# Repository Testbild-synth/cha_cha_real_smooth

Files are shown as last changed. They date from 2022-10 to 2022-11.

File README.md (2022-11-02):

# 4HP version of Voxmachina ChaCha VCLFO Eurorack module
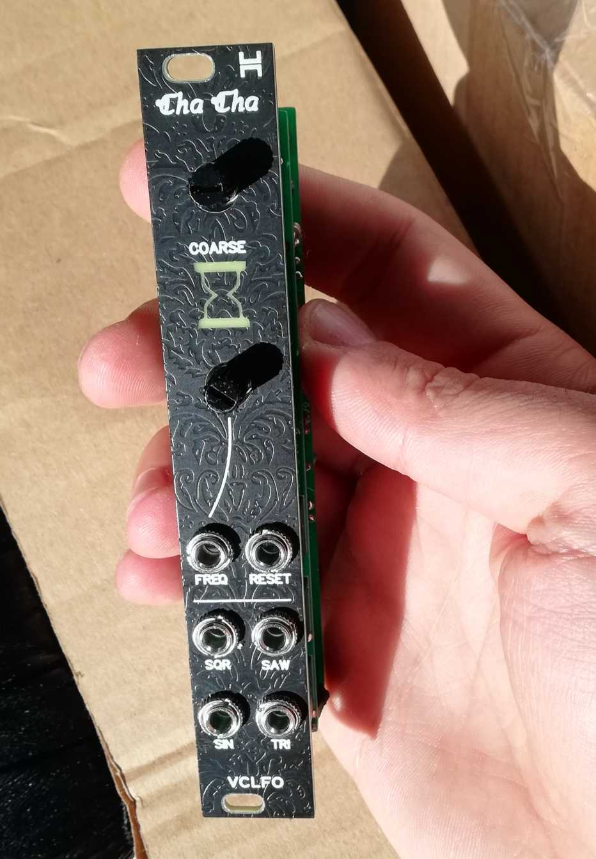
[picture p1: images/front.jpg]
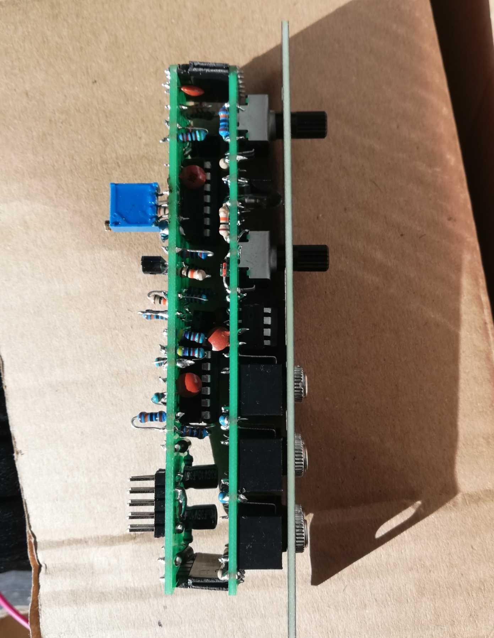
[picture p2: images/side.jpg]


This project is a 4HP fork of the Voxmachina chacha VCLFO eurorack module.

## Status: Confirmed working!

## Hardware and PCB

I had it in my head to do this in 4hp, but it was quite a pain.
In the end i had to fit a lot of standing resistors which I usually dislike but i think
I spaced them in a way that wasn't too confusing.

You can simply order the pcbs as-is on any pcb manufacturing site, 
I use jlcpcb. You can order all the pcbs with the standard settings.If for some reason the dimensions for the front panel
are not entered (happens to me sometimes on jlc), put them as 128.5x20mm.

  

The build is relatively straight forward, apart from the standing resistors which are kind of annoying.

schematic and bom are split between the two boards, as that's how voxmachina had his project set up. So just order components from both bom files

# Tuning
I simplified the sin shaping circuit so there is only one trimmer (for the saw shaper).
As for how to tune it, check out [voxmachina's videos on the module on youtube](https://www.youtube.com/watch?v=DsVzbcYWhuM&t=31s).

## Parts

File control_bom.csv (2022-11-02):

Name | Designator | Footprint | Quantity
0.1uf capacitor | C6,C7,C12 | RAD-0.1 | 3
CVIN, RESET, SINE, TRI, SQR, SAWUP | CV1, CV2, OUT1, OUT2, OUT3, OUT4 | THONKICONN | 6
1N4148 | D1,D5 | DO-35_BD2.0-L4.0-P8.00-D0.5-FD | 2
2.54mm header (female) 1x6 | H1 | 2.54mm header (female) 1x6 | 1
2.54mm header (female) 1x6 | H2 | 2.54mm header (female) 1x6 | 1
LED 5mm | LD1 | LED-TH_BD4.1-P2.00-D0.5-RD_RED | 1
BC550/BC548/equivalent | Q1,Q3 | BC547 | 2
4.7k resistor | R1 | AXIAL-0.3EZ | 1
330k resistor | R2 | AXIAL-0.3EZ | 1
B100k Potentiometer R09 | R3,R11 | R09-5KΩ | 2
100k resistor | R4,R8,R10,R14 | AXIAL-0.3EZ | 4
47k resistor | R5 | AXIAL-0.3EZ | 1
1k resistor | R7,R19,R20,R30,R41 | AXIAL-0.3EZ | 5
3.3k resistor | R17 | AXIAL-0.3EZ | 1
10k resistor | R21 | AXIAL-0.3EZ | 1
TL072 | IC1 | DIL08 | 1

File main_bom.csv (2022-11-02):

Name | Designator | Footprint | Quantity
10uF electrolytic capacitor | C1,C4,C8 | CAP-TH_BD5.0-P2.00-D0.8-FD | 3
0.1uf capacitor | C2,C3,C6,C7,C10 | RAD-0.1 | 5
1N4148 diode | D1,D2 | DO-35_BD2.0-L4.0-P8.00-D0.5-FD | 2
1N5819 diode | D3,D4 | DO-41_BD2.4-L4.7-P8.70-D0.9-RD | 2
2.54mm header (male) 6 pins | H1 | HDR-F-2.54_1X6 | 1
2.54mm header (male) 6 pins | H2 | HDR-F-2.54_1X6 | 1
Eurorack power header/2x5 header | P1 | EURORACK SHROUDED POWER 10 PIN | 1
BC550/BC548/equivalent | Q1,Q2 | TO92-X | 2
1k resistor | R1 | RESISTOR-VERTICAL | 1
10k resistor | R2,R14,R16,R20 | RESISTOR-VERTICAL | 4
39k resistor | R3 | RESISTOR-VERTICAL | 1
100k resistor | R4,R6,R7,R8,R15,R17,R19,R22 | RESISTOR-VERTICAL | 8
22k resistor | R5 | RESISTOR-VERTICAL | 1
47k resistor | R9,R10,R11,R12,R13 | RESISTOR-VERTICAL | 5
20k resistor | R18 | RESISTOR-VERTICAL | 1
51k resistor | R21 | RESISTOR-VERTICAL | 1
10 ohm resistor | R23,R24 | AXIAL-0.3 | 2
20k Trimpot | TM1 | TRIMPOT | 1
TL074 | U1,U2 | DIP-14 | 2

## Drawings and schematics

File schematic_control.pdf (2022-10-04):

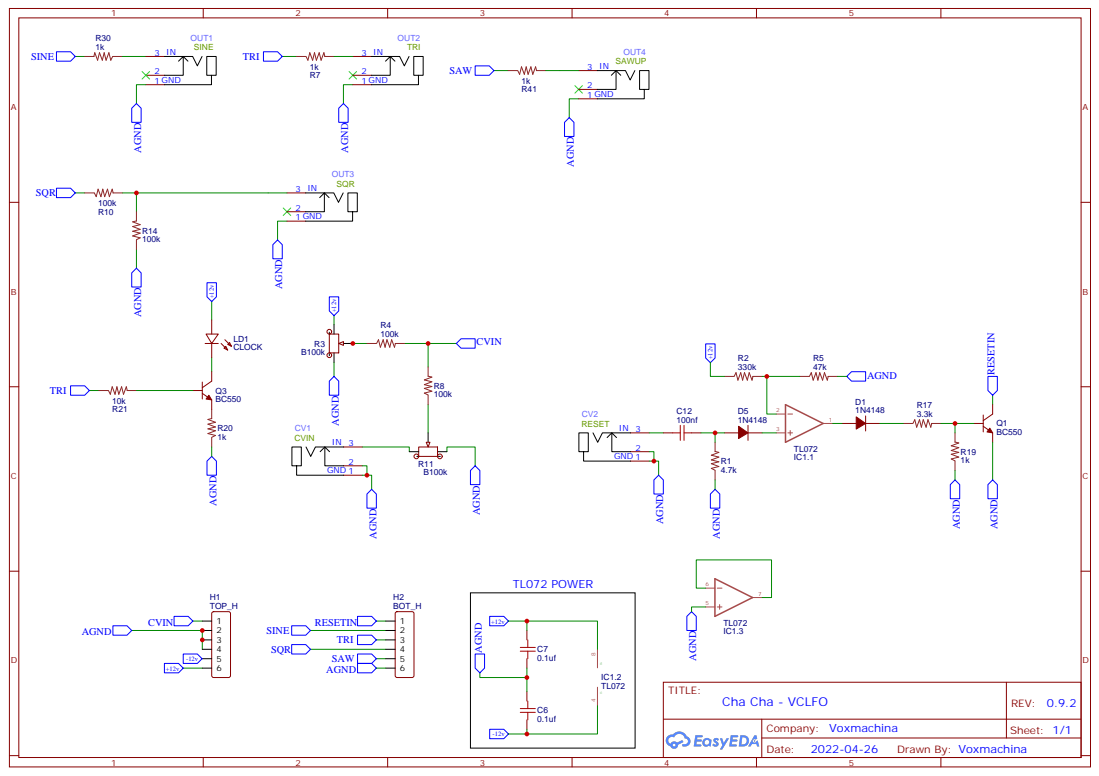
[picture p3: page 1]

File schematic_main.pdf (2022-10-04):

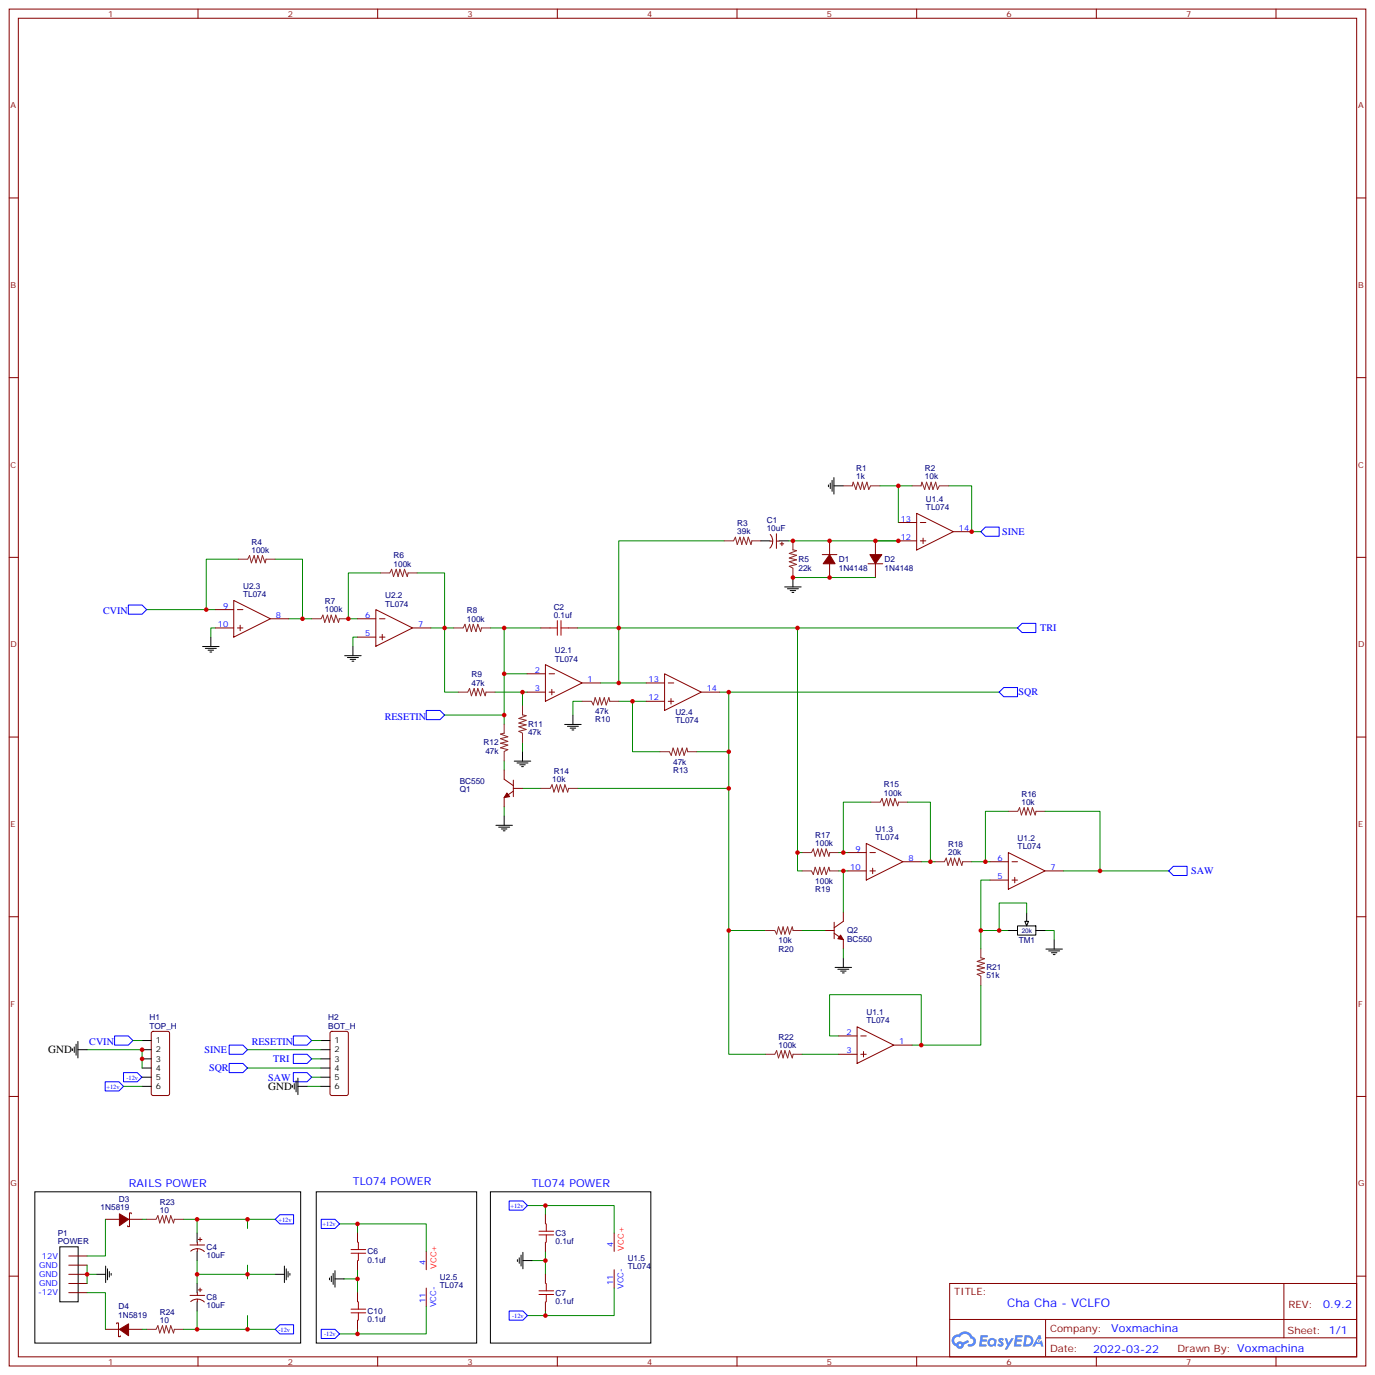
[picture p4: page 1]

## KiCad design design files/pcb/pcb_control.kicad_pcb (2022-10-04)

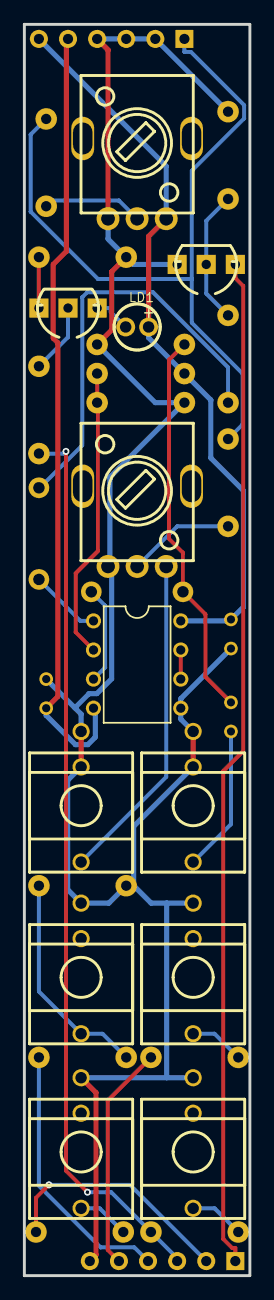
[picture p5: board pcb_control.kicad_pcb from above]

Board: 2 copper layers, 19.7 x 109.2 mm, 33 parts (0 on the bottom side), 27 nets.

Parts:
C6, C7, C12: 0.1uf; RAD-0.1
CV1: CVIN; THONKICONN
CV2: RESET; THONKICONN
D1, D5: 1N4148; DO-35_BD2.0-L4.0-P8.00-D0.5-FD
H1: TOP_H; HDR-F-2.54_1X6
H2: BOT_H; HDR-F-2.54_1X6
IC1: TL072; DIL08
LD1: CLOCK; LED-TH_BD4.1-P2.00-D0.5-RD_RED
OUT1: SINE; THONKICONN
OUT2: TRI; THONKICONN
OUT3: SQR; THONKICONN
OUT4: SAWUP; THONKICONN
Q1, Q3: BC550; BC547
R1: 4.7k; AXIAL-0.3EZ
R2: 330k; AXIAL-0.3EZ
R3, R11: B100k; R09-5KΩ
R4, R8, R10, R14: 100k; AXIAL-0.3EZ
R5: 47k; AXIAL-0.3EZ
R7, R19, R20, R30, R41: 1k; AXIAL-0.3EZ
R17: 3.3k; AXIAL-0.3EZ
R21: 10k; AXIAL-0.3EZ

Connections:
+12V: C7.2, H1.6, IC1.8, LD1.2, R2.1, R3.3
-12V: C6.1, H1.5, IC1.4
AGND: C6.2, C7.1, CV1.1, CV1.2, CV2.1, CV2.2, H1.2, H1.3, H1.4, H2.6, IC1.5, OUT1.1, OUT2.1, OUT3.1, OUT4.1, Q1.3, R1.1, R3.1, R5.2, R11.1, R14.1, R19.1, R20.1
C12_2: C12.2, D5.1, R1.2
CV1_3: CV1.3, R11.3
CV2_3: C12.1, CV2.3
CVIN: H1.1, R4.2, R8.2
D5_2: D5.2, IC1.3
IC1_1: D1.1, IC1.1
IC1_2: IC1.2, R2.2, R5.1
IC1_6: IC1.6, IC1.7
Q3_1: LD1.1, Q3.1
Q3_2: Q3.2, R21.2
R4_1: R3.2, R4.1
R7_2: OUT2.3, R7.2
R8_1: R8.1, R11.2
R14_2: OUT3.3, R10.2, R14.2
R17_1: D1.2, R17.1
R17_2: Q1.2, R17.2, R19.2
R20_2: Q3.3, R20.2
R30_1: OUT1.3, R30.1
R41_2: OUT4.3, R41.2
RESETIN: H2.1, Q1.1
SAW: H2.5, R41.1
SINE: H2.2, R30.2
SQR: H2.4, R10.1
TRI: H2.3, R7.1, R21.1

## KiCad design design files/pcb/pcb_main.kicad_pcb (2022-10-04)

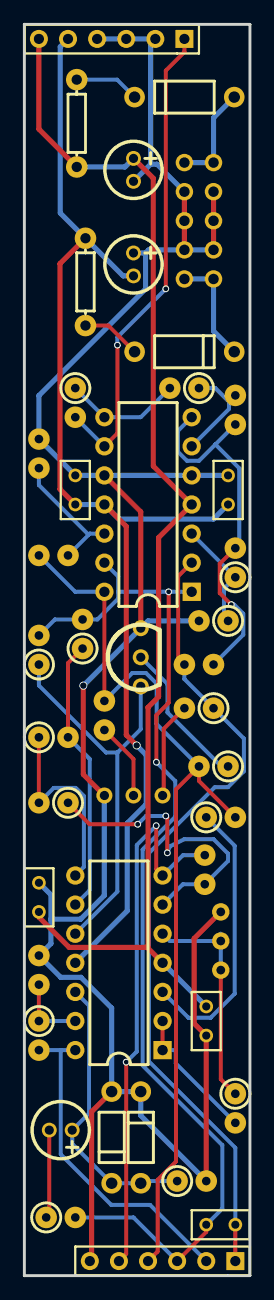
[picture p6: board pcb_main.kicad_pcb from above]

Board: 2 copper layers, 19.7 x 109.2 mm, 44 parts (0 on the bottom side), 31 nets.

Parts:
C1, C4, C8: 10uF; CAP-TH_BD5.0-P2.00-D0.8-FD
C2, C3, C6, C7, C10: 0.1uf; RAD-0.1
D1, D2: 1N4148; DO-35_BD2.0-L4.0-P8.00-D0.5-FD
D3, D4: 1N5819; DO-41_BD2.4-L4.7-P8.70-D0.9-RD
H1: TOP_H; HDR-F-2.54_1X6
H2: BOT_H; HDR-F-2.54_1X6
P1: POWER; EURORACK SHROUDED POWER 10 PIN
Q1, Q2: BC550; TO92-X
R1: 1k; RESISTOR-VERTICAL
R2, R14, R16, R20: 10k; RESISTOR-VERTICAL
R3: 39k; RESISTOR-VERTICAL
R4, R6, R7, R8, R15, R17, R19, R22: 100k; RESISTOR-VERTICAL
R5: 22k; RESISTOR-VERTICAL
R9, R10, R11, R12, R13: 47k; RESISTOR-VERTICAL
R18: 20k; RESISTOR-VERTICAL
R21: 51k; RESISTOR-VERTICAL
R23, R24: 10; AXIAL-0.3
TM1: 20k; TRIMPOT
U1, U2: TL074; DIP-14

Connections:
+12V: C3.2, C4.1, C6.2, H1.6, R23.2, U1.4, U2.4
-12V: C7.1, C8.2, C10.1, H1.5, R24.2, U1.11, U2.11
CVIN: H1.1, R4.1, U2.9
D3_1: D3.1, R23.1
D4_2: D4.2, R24.1
GND: C3.1, C4.2, C6.1, C7.2, C8.1, C10.2, D1.1, D2.2, H1.2, H1.3, H1.4, H2.6, P1.2, P1.3, P1.4, Q1.3, Q2.3, R1.2, R5.1, R10.1, R11.1, TM1.1, U2.5, U2.10
P1_1: D3.2, P1.1
P1_5: D4.1, P1.5
Q1_1: Q1.1, R12.1
Q2_2: Q2.2, R20.2
R3_2: C1.2, R3.2
R6_1: R6.1, R7.2, U2.6
R7_1: R4.2, R7.1, U2.8
R9_1: R6.2, R8.1, R9.1, U2.7
R10_2: R10.2, R13.1, U2.12
R11_2: R9.2, R11.2, U2.3
R14_1: Q1.2, R14.1
R15_2: R15.2, R18.1, U1.8
R17_2: R15.1, R17.2, U1.9
R19_2: Q2.1, R19.2, U1.10
R21_1: R21.1, U1.1, U1.2
R22_2: R22.2, U1.3
RESETIN: C2.2, H2.1, R8.2, R12.2, U2.2
SAW: H2.5, R16.2, U1.7
SINE: H2.2, R2.1, U1.14
SQR: H2.4, R13.2, R14.2, R20.1, R22.1, U2.14
TRI: C2.1, H2.3, R3.1, R17.1, R19.1, U2.1, U2.13
U1_5: R21.2, TM1.2, TM1.3, U1.5
U1_6: R16.1, R18.2, U1.6
U1_12: C1.1, D1.2, D2.1, R5.2, U1.12
U1_13: R1.1, R2.2, U1.13

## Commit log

2022-11-02 Updated main pcb
2022-11-02 added annotations to pcbs
